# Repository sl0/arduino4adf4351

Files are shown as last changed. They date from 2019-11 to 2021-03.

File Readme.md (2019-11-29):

# ArduinoNano for ADF4351

## Handy tool for flexible configuration of ADF4351

An Arduino Nano is used to set ADF4351 Registers to determine the
Synthesizers output frequency.

### Software License

The ard4adf.ino file is licensed under the terms of
GNU General Public License version 3 or later.

For KiCAD the footprint and library modules of the voltage-regulator
chips are found on the net with unknown licenses, so they are not
included here. Files in the kicad directory are 'Open Source' under
the terms of the definition for Open Source Hardware Association.

    http://www.oshwa.org/definition/

## Arduino sketch

Host (DK2KA) build various Synthesizer solutions – based on
handwired hardware PoC for GHz Beacons, AO 100 and 10 GHz EME HAM
Radio Devices – Arduino Sketches included.
Wolf (DF7KB) suggested modifications to ease assembling the PCBs,
especially to create a backpack solution that fits exactly onto
the Synthesizer breakout board.

A solution to select a variety of frequencies from the Synthesizer
has been added.  Aim was to generate Local Oscillator frequencies
for Transverters, synchronizing them with GPS and therefore
preparing the HAM Equipment for frequency accuracy and weak signal
operations.

The Sketch was transformed into an „easyly readable code“ to allow
adaptations on the fly.

Finally the ADF4351 evaluation board was extended with the Arduino
NANO Hardware to create a handy solution to set the synthezisers
registers. At the same time debugging elements have been added.

### Compiling and debugging - Sketch: ard4adf.ino

The ard4adf.ino can be compiled and loaded into an Arduino-Nano.

#### Debug via Serial Monitor

For testing just use the serial monitor of ardunio-IDE, if
the line

    //#define DEBUG_VIA_SERIAL

is uncommented at compile time.

#### Debug via Blinking Arduino Led

Another useful debugging feature is implented by using the led on the
arduino board. Repeating one second led-on mean the LE pin is low, so
ADF4351 is signaling PLL sync is lost. Short flickers should be
counted after a three second pause, the number indicates the jumpers
reading and so you can easily read the frequency on ADF4351 outputs
(in a binary way).

There are 3 jumpers read as 3 bits, so its 0 .. 7, 8 possible settings.
Jumper set means bit is set to low. Jumper not set means bit is set to
high.

    1 flicker and 3 sec pause <==> jumpers are evaluated to 0.
    2 flickers and 3 sec pause <==> jumpers are evaluated to 1
    ...
    8 flickers and 3 sec pause <==> jumper s are evaluated to 7

The flickering is always on.

## KiCAD-PCB

The KiCAD schema and PCB-layout may be found in the directory kicad.
**ADM7150ARDZ-3.3** and **ADM7150ARDZ-5.0** are voltage regulators
used to achieve  low noise power supplies on the arduino and the
ADF4351 chips. The board may be powered with some 6 to 7 V DC. It
is assembled in a mixture of conventional and SMD parts.

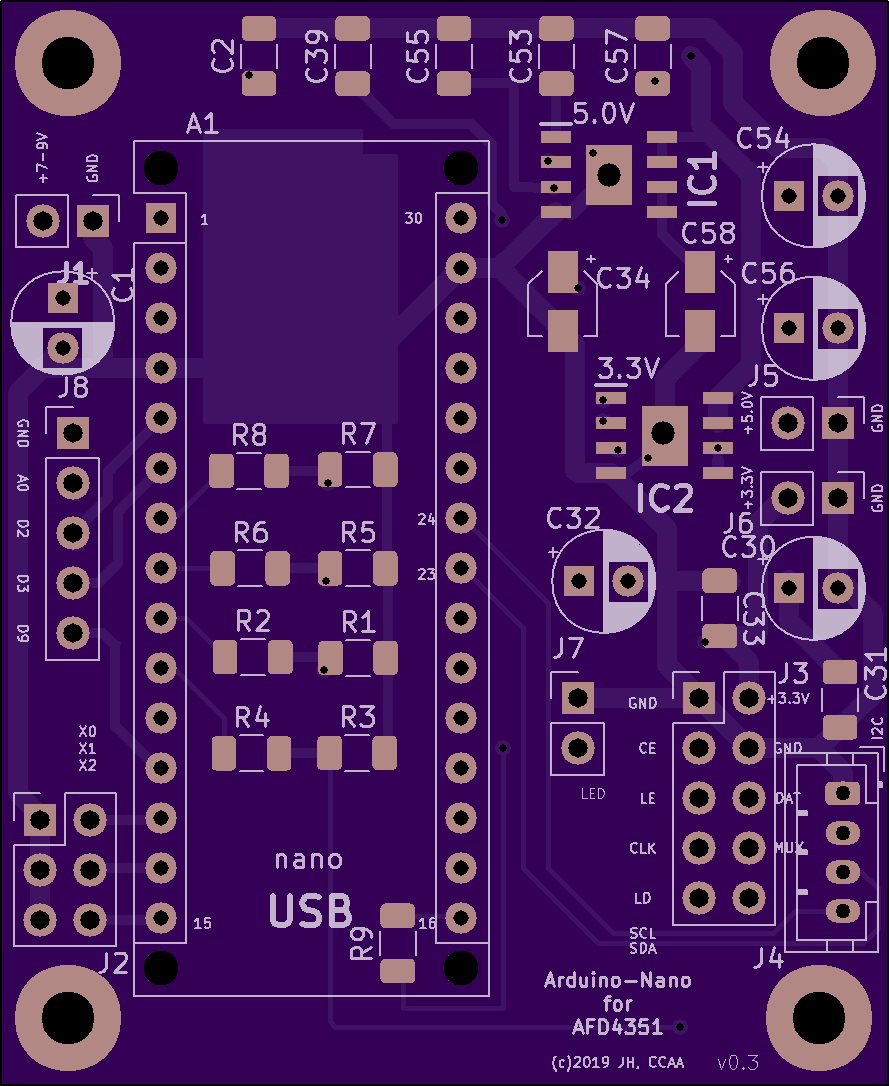
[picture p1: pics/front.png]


Have fun!

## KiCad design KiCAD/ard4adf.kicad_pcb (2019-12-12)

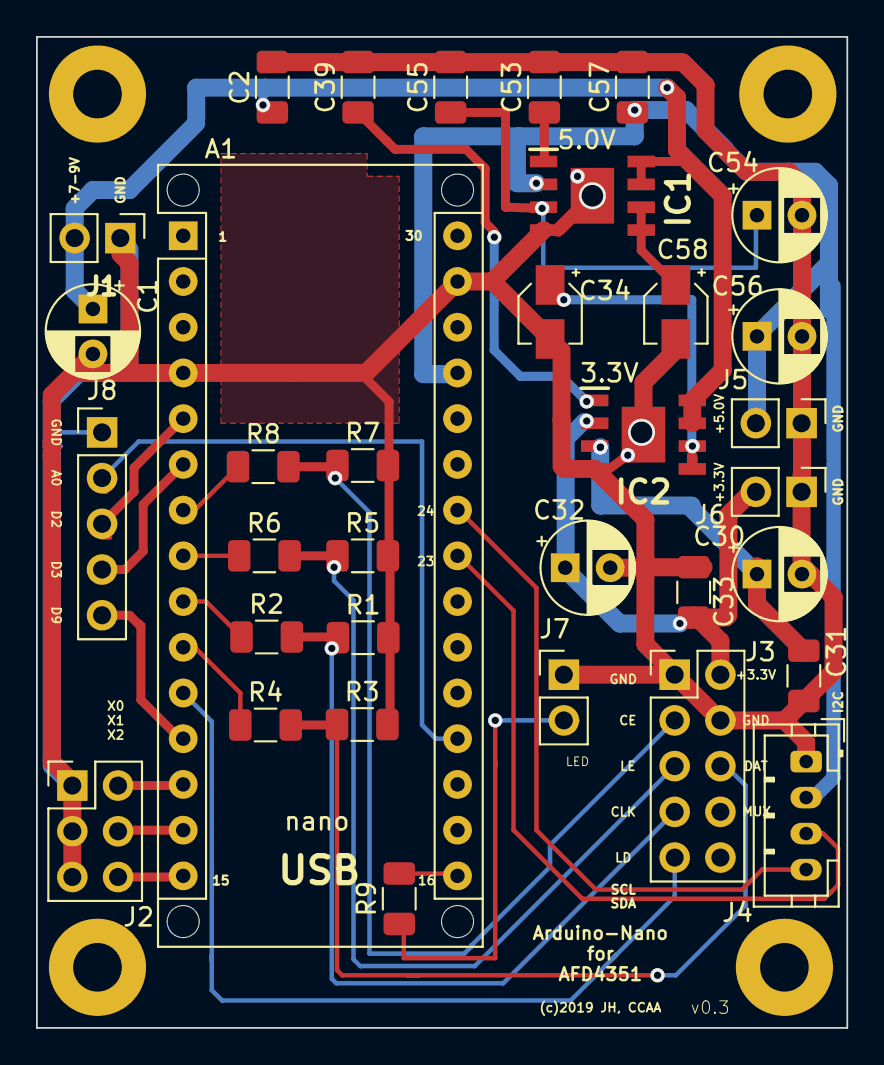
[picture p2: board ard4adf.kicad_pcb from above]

Board: 2 copper layers, 45.0 x 55.1 mm, 34 parts (0 on the bottom side), 30 nets.

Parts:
A1: Arduino_Nano_v3.x; Arduino_Nano_WithMountingHoles
C1, C30, C32, C54, C56: 47uF; CP_Radial_D5.0mm_P2.50mm
C2, C31, C33, C39, C53, C55, C57: 10nF; C_1206_3216Metric
C34, C58: 1uF; CP_Elec_3x5.3
IC1: ADM7150ARDZ-5.0; SOIC127P600X175-9N
IC2: ADM7150ARDZ-3.3; SOIC127P600X175-9N
J1, J5, J6, J7: Conn_01x02_Male; PinHeader_1x02_P2.54mm_Vertical
J2: Conn_02x03_Odd_Even; PinHeader_2x03_P2.54mm_Vertical
J3: Conn_02x05_Top_Bottom; PinHeader_2x05_P2.54mm_Vertical
J4: Conn_01x04_Male; JST_PH_B4B-PH-K_1x04_P2.00mm_Vertical
J8: Conn_01x05_Male; PinHeader_1x05_P2.54mm_Vertical
R1, R3, R5, R7: 3k3; R_1206_3216Metric
R2, R4, R6, R8: 1k5; R_1206_3216Metric
R9: 220; R_1206_3216Metric

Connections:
GND: A1.4, A1.29, C1.2, C2.2, C30.2, C31.2, C32.2, C33.2, C34.2, C39.2, C53.2, C54.2, C55.2, C56.2, C57.2, C58.2, IC1.4, IC1.9, IC2.4, IC2.9, J1.1, J2.1, J2.3, J2.5, J3.1, J3.4, J4.1, J5.1, J6.1, J7.1, J8.1, R1.2, R3.2, R5.2, R7.2
unnamed: A1.5, J8.3
unnamed: A1.6, J8.4
unnamed: A1.7, R8.1
unnamed: A1.8, R6.1
unnamed: A1.9, R2.1
unnamed: A1.10, R4.1
unnamed: A1.11, J3.9
unnamed: A1.12, J8.5
unnamed: A1.13, J2.2
unnamed: A1.14, J2.4
unnamed: A1.15, J2.6
unnamed: A1.16, R9.2
unnamed: A1.19, J8.2
unnamed: A1.23, J4.3
unnamed: A1.24, J4.4
unnamed: A1.27, C56.1, C57.1, IC1.2, J4.2, J5.2
unnamed: C1.1, C2.1, IC1.7, IC1.8, IC2.7, IC2.8, J1.2
unnamed: C30.1, C31.1, IC2.3
unnamed: C32.1, C33.1, IC2.2, J3.2, J6.2
unnamed: C34.1, IC2.5, IC2.6
unnamed: C39.1, IC2.1
unnamed: C53.1, IC1.1
unnamed: C54.1, C55.1, IC1.3
unnamed: C58.1, IC1.5, IC1.6
unnamed: J3.3, R7.1, R8.2
unnamed: J3.5, R5.1, R6.2
unnamed: J3.6, R3.1, R4.2
unnamed: J3.7, R1.1, R2.2
unnamed: J7.2, R9.1

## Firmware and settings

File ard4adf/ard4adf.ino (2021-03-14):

/* ********************************************************************
 * Arduino sketch to handle an ADF4351 Synthesizer chip
 *
 * Intention:   Tool for easy generation of fixed frequencies
 *
 * First draft: 2016-08-01 by DK2KA (H.G.Thum) on arduino ProMini
 *              handwired proof of concept worked well
 *
 * Proposals:   2019-09 DF7KB, Wolf Pueschner suggested to have jumpers
 *              to set different fixed frequencies into the adf chip
 *
 * Revision:    2019-11-29 by sl0, ccaa
 *              some parts have been rewritten, defines for this and that
 *              now compiles on arduino-1.8.10
 *
 * Finally:     Have 3 jumpers to select a frequency out of a set of 8
 *              Have debugging features, like serial printstmts and
 *              and flickering arduino-led to debug without adf plugged
 *              Added an i2c connector for future use
 *
 * License:     GNU General Public License version 3 or later
 *
 * Background:  Datasheet from Analog devices: ADF4351 (Rev. A)
 * https://www.analog.com/media/en/technical-documentation/data-sheets/ADF4351.pdf
 *
 * ******************************************************************** */

// uncommend following line to have debug output on serial interface
//#define DEBUG_VIA_SERIAL

// arduino default LED
#define Led_Pin 13      // arduino LED hardwired for blinking

// 3 jumpers, so we have eight possible settings 0..7
#define X0_Pin 10       // jumper 1 is LOW or HIGH
#define X1_Pin 11       // jumper 2 is LOW or HIGH
#define X2_Pin 12       // jumper 3 is LOW or HIGH

// name arduino-(J2)      adf-pin(J1==J5)  meaning                ADF4351 datasheet page
#define CE_Pin      4   // 2  chip enable, low powers down the chip        (DS7, Pin 4)
#define LE_Pin      5   // 3  load enable, high load register selected     (DS7, Pin 3)
#define CLK_Pin     6   // 4  clock to shift in data                       (DS7, Pin 1)
#define DATA_Pin    7   // 8  Serial Data goes here                        (DS7, Pin 2)
#define LD_Pin      8   // 9  ADF LED or PLL Lock output, High OK          (DS8, Pin 25)

// useful abbreviations
#define pulseHigh(pin)  {digitalWrite(pin, 1); digitalWrite(pin, 0); }
#define pulseLow(pin)   {digitalWrite(pin, 0); digitalWrite(pin, 1); }
#define Led_On          {digitalWrite(Led_Pin, HIGH);}
#define Led_Off         {digitalWrite(Led_Pin, LOW);}
#define BLINK_ONCE      {Led_On; delay(20); Led_Off; delay(50);}

int ld_value;           // reperesents LD_Pin (for debug output)
int jumper_value;       // actual value calculated from X0 and X1 and x2
int jumper_old;         // to be compared to, if chgd, do stuff again
int jumpers;            // accumulation

int X0;                 //  v_0=1 jumper_value =  X0 * v_0 + X1 * v_1 + X2 * v_2
int X1;                 //  v_1=2    with X0,X1,X2 each [ 0 | 1 ]
int X2;                 //  v_2=4    on that Input-Pin

int read_jumpers() {
    // evaluate the three jumpers at once
    X0 = (!digitalRead(X0_Pin)) & 0x01;
    X1 = (!digitalRead(X1_Pin)) & 0x01;
    X2 = (!digitalRead(X2_Pin)) & 0x01;
    jumpers = X0  + (X1 * 2) + (X2 * 4);
#ifdef DEBUG_VIA_SERIAL
    Serial.print("Read jumpers:");
    Serial.println(jumpers);
#endif
    return jumpers;
}

void flicker(int n) {
    // possible jumper_values are { 0 .. 7 }, so we need 1 .. 8 flashes!
    int i;
    for(i=0; i <= n; i++) {
        BLINK_ONCE;
#ifdef DEBUG_VIA_SERIAL
        Serial.print("BLINK ");
        Serial.println(i);
#endif
        delay(400);
    }
}

void ADF4351_Init() {
#ifdef DEBUG_VIA_SERIAL
    Serial.println("\n\nADF4351 initializing ...");
#endif
    // set initial values on the pins
    digitalWrite(CE_Pin, HIGH);
    digitalWrite(LE_Pin, LOW);
    digitalWrite(CLK_Pin, LOW);
    digitalWrite(DATA_Pin, LOW);
}

void ADF4351_Reset() {
#ifdef DEBUG_VIA_SERIAL
    Serial.println("soft reset: ADF4351");
#endif
    pulseLow(CE_Pin);   // reset signal
    delay(1);
    pulseHigh(CLK_Pin); // clock signal
    delay(1);
    pulseHigh(LE_Pin);  // frequency update signal
#ifdef DEBUG_VIA_SERIAL
    Serial.println("soft reset: ADF4351 ready");
#endif
}

void ADF4351_SendData(int c) {
    for (int i = 7; i >= 0; i--) {      // LSB-MSB (i = 0; i >8 ; i++)
        digitalWrite(DATA_Pin, (c >> i) & 0x01);
        pulseHigh(CLK_Pin);
    }
}

void ADF4351_Frequenz(long frequenz) {
    long  y;
    y = frequenz;
    ADF4351_SendData((y >> 24) & 0xFF); //  send MSB first
    ADF4351_SendData((y >> 16) & 0xFF);
    ADF4351_SendData((y >> 8)  & 0xFF);
    ADF4351_SendData((y ) & 0xFF);      // send LSB last
    pulseHigh(LE_Pin);                  // set registers are valid
}

void set_freq_0() {                 //  calculated for 10 MHz Ref.
#ifdef DEBUG_VIA_SERIAL
    Serial.println("ADF4351 set freq 0 command");
#endif
// Q:10 Freq: 1728.001MHz
//                i=5=> 00580005
    ADF4351_Frequenz( 0x00580005);  // Reg 5
//                i=4=> 009c8024
    ADF4351_Frequenz( 0x009c8024);  // Reg 4
//                i=3=> 000004b3
    ADF4351_Frequenz( 0x000004B3);  // Reg 3
//                i=2=> 18004e42
    ADF4351_Frequenz( 0x18004e42);  // Reg 2
//                i=1=> 08001f41
    ADF4351_Frequenz( 0x08001f41);  // Reg 1
//                i=0=> 00ac92c0
    ADF4351_Frequenz( 0x00ac92c0);  // Reg 0
}

void set_freq_1() {                 //  calculated for 10 MHz Ref.
#ifdef DEBUG_VIA_SERIAL
    Serial.println("ADF4351 set freq 1 command");
#endif
//Q:10 Freq: 1748.250MHz
//                i=5=> 00580005
    ADF4351_Frequenz( 0x00580005);  // Reg 5
//                i=4=> 009c8024
    ADF4351_Frequenz( 0x009c8024);  // Reg 4
//                i=3=> 000004b3
    ADF4351_Frequenz( 0x000004B3);  // Reg 3
//                i=2=> 18004e42
    ADF4351_Frequenz( 0x18004e42);  // Reg 2
//                i=1=> 08001f41
    ADF4351_Frequenz( 0x08001f41);  // Reg 1
//                i=0=> 00ae9450
    ADF4351_Frequenz( 0x00ae9450);  // Reg 0
}

void set_freq_2() {                 //  calculated for 10 MHz Ref.
#ifdef DEBUG_VIA_SERIAL
    Serial.println("ADF4351 set freq 2 command");
#endif
//Q:10 Freq: 40.00MHz RFstep: 10.000kHz Regs:   00580005  00ec803c  000004b3  18004e42  08001f41  00800000

    ADF4351_Frequenz( 0x00580005);  // Reg 5
    ADF4351_Frequenz( 0x00ec803c);  // Reg 4
    ADF4351_Frequenz( 0x000004B3);  // Reg 3
    ADF4351_Frequenz( 0x18004e42);  // Reg 2
    ADF4351_Frequenz( 0x08001f41);  // Reg 1
    ADF4351_Frequenz( 0x00800000);  // Reg 0   40.000.000,0 Hz
}

void set_freq_3() {                 //  calculated for 10 MHz Ref.
#ifdef DEBUG_VIA_SERIAL
    Serial.println("ADF4351 set freq 3 command");
#endif
    ADF4351_Frequenz( 0x00580005);  // Reg 5
    ADF4351_Frequenz( 0x0091043C);  // Reg 4
    ADF4351_Frequenz( 0x000004B3);  // Reg 3
    ADF4351_Frequenz( 0x18015E42);  // Reg 2
    ADF4351_Frequenz( 0x08009F41);  // Reg 1
    ADF4351_Frequenz( 0x02400000);  // Reg 0   1.152.000.000,0 Hz
}

void set_freq_4() {                 //  calculated for 10 MHz Ref.
#ifdef DEBUG_VIA_SERIAL
    Serial.println("ADF4351 set freq 4 command");
#endif
    ADF4351_Frequenz( 0x00580005);  // Reg 5
    ADF4351_Frequenz( 0x0091043C);  // Reg 4
    ADF4351_Frequenz( 0x000004B3);  // Reg 3
    ADF4351_Frequenz( 0x18015E42);  // Reg 2
    ADF4351_Frequenz( 0x08008FA1);  // Reg 1
    ADF4351_Frequenz( 0x026F0000);  // Reg 0   1.246.000.000,0 Hz
}

void set_freq_5() {                 //  calculated for 10 MHz Ref.
#ifdef DEBUG_VIA_SERIAL
    Serial.println("ADF4351 set freq 5 command");
#endif
//Q:10 Freq: 1296.10MHz RFstep: 10.000kHz Regs:   00580005  009c803c  000004b3  18004e42  08001f41  008186e0
    ADF4351_Frequenz( 0x00580005);  // Reg 5
    ADF4351_Frequenz( 0x009c803c);  // Reg 4
    ADF4351_Frequenz( 0x000004B3);  // Reg 3
    ADF4351_Frequenz( 0x18004e42);  // Reg 2
    ADF4351_Frequenz( 0x08001f41);  // Reg 1
    ADF4351_Frequenz( 0x008186e0);  // Reg 0  1296.100.000,0 Hz
}

void set_freq_6() {                 //  calcd for 10 MHz Ref.
#ifdef DEBUG_VIA_SERIAL
    Serial.println("ADF4351 set freq 6 command");
#endif
//Q:10 Freq:  432.10MHz RFstep: 10.000kHz Regs:   00580005  00bc803c  000004b3  18004e42  08001f41  00ac9540
    ADF4351_Frequenz( 0x00580005);  // Reg 5
    ADF4351_Frequenz( 0x00bc803c);  // Reg 4
    ADF4351_Frequenz( 0x000004B3);  // Reg 3
    ADF4351_Frequenz( 0x18004e42);  // Reg 2
    ADF4351_Frequenz( 0x08001f41);  // Reg 1
    ADF4351_Frequenz( 0x00ac9540);  // Reg 0
}

void set_freq_7() {                 //  calcd for 10 MHz Ref.
#ifdef DEBUG_VIA_SERIAL
    Serial.println("ADF4351 set freq 7 command");
#endif
//Q:10 Freq: 2320.10MHz RFstep: 10.000kHz Regs:   00580005  008c803c  000004b3  18004e42  08001f41  00740050
    ADF4351_Frequenz( 0x00580005);  // Reg 5
    ADF4351_Frequenz( 0x008c803c);  // Reg 4
    ADF4351_Frequenz( 0x000004B3);  // Reg 3
    ADF4351_Frequenz( 0x18004e42);  // Reg 2
    ADF4351_Frequenz( 0x08001f41);  // Reg 1
    ADF4351_Frequenz( 0x00740050);  // Reg 0
}

// Arduino needs this setup function
void setup() {
#ifdef DEBUG_VIA_SERIAL
    Serial.begin(57600);
    for (int i=0; i<40; i++) Serial.println();
    Serial.println("Hard reset encountered\n\nentering setup for Arduino-for-ADF4351");
#endif
    pinMode(Led_Pin, OUTPUT);       // LED Arduino
    pinMode(LD_Pin, INPUT_PULLUP);  // PLL valid, high == OK
    pinMode(CE_Pin, OUTPUT);        // chip enable
    pinMode(LE_Pin, OUTPUT);        // load enable
    pinMode(CLK_Pin, OUTPUT);       // clock
    pinMode(DATA_Pin, OUTPUT);      // data

    pinMode(X0_Pin, INPUT_PULLUP);  //  selector 2**0
    pinMode(X1_Pin, INPUT_PULLUP);  //  selector 2**1
    pinMode(X2_Pin, INPUT_PULLUP);  //  selector 2**2
#ifdef DEBUG_VIA_SERIAL
    Serial.println("All I/O modes are set now");
#endif

    ADF4351_Reset();
    delay(10);                      // spend time to relax from that shock
    ADF4351_Init();
    delay(500);                     // spend time for his initial work
    jumper_value = read_jumpers();  // read the jumper setting
    jumper_old = 10;                // force evaluation of the jumpers on every hard reset
#ifdef DEBUG_VIA_SERIAL
    Serial.println("Arduino-for-ADF4351 setup ready, start to loop");
#endif
}

//  Main application loop follows
void loop()
{
    jumper_value = read_jumpers();  // read the jumper setting
    flicker(jumper_value);          // flash the led at countable speed

    // LD_Pin low means PLL fault, ==> try to reset the chip
    ld_value = digitalRead(LD_Pin);
#ifdef DEBUG_VIA_SERIAL
    Serial.print("LD:");
    Serial.println(ld_value, HEX);
#endif
    if (!ld_value) {
#ifdef DEBUG_VIA_SERIAL
    Serial.println("\nfound low voltage on LD_Pin, resetting ard4351");
#endif
        Led_On
        delay(1000);
        ADF4351_Reset();
        delay(10);
        ADF4351_Init();
        delay(500);
        jumper_old = 10;  // force evaluating jumpers on every reset
    }

    if (jumper_value == jumper_old) {
#ifdef DEBUG_VIA_SERIAL
    Serial.println("loop, no change");
#endif
        delay(3000);                // do nothing for a three seconds
    } else {
        jumper_old = jumper_value;  // but do it only once!
#ifdef DEBUG_VIA_SERIAL
    Serial.print("jumpers read: ");
    Serial.println(jumper_value, HEX);
#endif
        switch(jumper_value) {
            case 0: set_freq_0();   // 1728.000 MHz - 10MHz Ref.
                    break;
            case 1: set_freq_1();   // 1748.250 MHz - 10MHz Ref.
                    break;
            case 2: set_freq_2();   //  144.0 MHz  - 10MHz Ref.
                    break;
            case 3: set_freq_3();   // 1152.0 MHz  - 10MHz Ref.
                    break;
            case 4: set_freq_4();   // 1246.0 MHz  - 10MHz Ref.
                    break;
            case 5: set_freq_5();   //  180.0 MHz  - 10MHz Ref.
                    break;
            case 6: set_freq_6();   //  432.1 MHz  - 10MHz Ref.
                    break;
            case 7: set_freq_7();   // 2320.1 MHz  - 10MHz Ref.
                    break;
        }
    }
}
// EoF

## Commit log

2019-11-29 Adds first arduino sketch to control the beast
    It is working as designed first time on 2019-11-28 (very first bugs fixed)
    [ard4adf.ino]
2019-11-29 Adds PCB prototype and schema
    Included: 5.0V and 3.3V regulators and a socket for an Arduino-Nano
    [ard4adf.kicad_pcb, ard4adf.sch]
2019-12-01 Ensure Arduino-IDE is satisfied: changed dir-name
2019-12-01 Adds R(220) and output-pins J7 for external LED
    [ard4adf.kicad_pcb, ard4adf.sch]
2019-12-12 Updates PCB to newest order
    Adds 5-pin connector: A0, D2, D3, D9
    [ard4adf.kicad_pcb, ard4adf.sch]
2019-12-12 Updates PCB picture (used in Readme.md)
2021-03-14 Upgrades to Kicad 5.1.9 backport from sid
2021-03-14 Changes first two freqs to 1728.000 and 1748.250 MHz
    Take these times 6 to check 3cm band LNBs

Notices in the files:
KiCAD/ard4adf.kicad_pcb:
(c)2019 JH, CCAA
